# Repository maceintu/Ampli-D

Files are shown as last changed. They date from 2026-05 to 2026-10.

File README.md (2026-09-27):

# Ampli-D

Amplificateur audio stéréo **classe D** open hardware : entrées filaires et Bluetooth, DAC audiophile,
pilotage par microcontrôleur STM32. Le dépôt contient l'ensemble de la conception — schémas, PCB et firmware.

> **État du projet :** conception matérielle terminée côté schémas, routage du PCB en cours,
> firmware au stade du squelette généré (STM32CubeMX).

---

## Aperçu

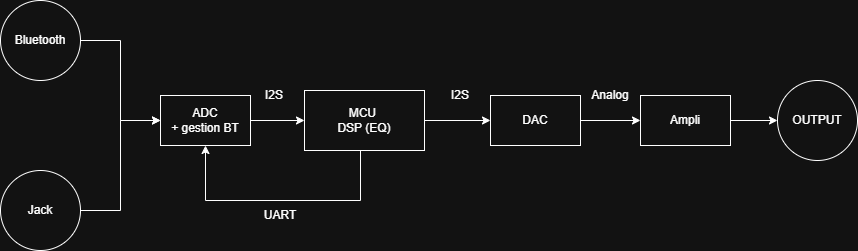
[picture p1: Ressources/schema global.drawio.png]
Schéma global


## Caractéristiques

| Bloc | Composant principal | Rôle |
|---|---|---|
| **Amplification** | TI **TPA3255** (DDV) | Étage de puissance classe D stéréo, filtres de sortie 10 µH / 25 A |
| **DAC** | TI **PCM5242** | Conversion I2S → analogique différentiel, sortie directe vers l'ampli |
| **Sélecteur de source** | TI **TMUX1574** | Aiguillage des flux I2S (filaire / Bluetooth) |
| **Entrées filaires** | TI **PCM1863** | 3 entrées stéréo numérisées (jacks Neutrik NMJ4HFD2 + jack 3,5 mm) |
| **Bluetooth** | **FSC-BT1058** | Réception audio sans fil (I2S) + contrôle par UART |
| **Contrôle** | ST **STM32G030C8T6** | Sélection de source, volume/EQ via I2C, appairage BT, gestion des défauts |
| **Alimentation** | LM5017 · TLV76733 · LT3042 | 36–48 V d'entrée → 12 V → 3,3 V numérique + 3,3 V analogique faible bruit |

**Interface utilisateur :** commutateur rotatif 4 positions (source), bouton poussoir (appairage Bluetooth),
4 potentiomètres lus par l'ADC du STM32 (volume et égalisation).

## Structure du dépôt

```
Ampli-D/
├── Kicad Workspace/        # Projet KiCad 10 (schémas hiérarchiques + PCB 2 couches)
│   ├── alimentation.kicad_sch
│   ├── amplification.kicad_sch
│   ├── bluetooth.kicad_sch
│   ├── eq_and_dac.kicad_sch
│   ├── mcu.kicad_sch
│   ├── wired_input.kicad_sch
│   ├── Components Lib.kicad_sym    # Symboles personnalisés
│   ├── FootPrints.pretty/          # Empreintes personnalisées
│   └── Lib Import/                 # Symboles / empreintes / STEP fabricants
├── STM32 Workspace/        # Projet STM32CubeIDE (STM32G030C8T6)
│   ├── MCU.ioc                     # Configuration CubeMX
│   ├── Core/                       # Code applicatif
│   └── Drivers/                    # HAL STM32G0 + CMSIS
└── Ressources/             # Datasheets, modèles 3D, outils de calcul
```

## Alimentation

| Rail | Régulateur | Usage |
|---|---|---|
| 36 V / 48 V | entrée externe | PVDD du TPA3255 |
| 12 V | LM5017 (buck 100 V) | GVDD / pilotage de l'étage de puissance |
| 3,3 V | TLV76733 | Numérique (STM32, Bluetooth) |
| 3,3 V A | LT3042 (LDO ultra faible bruit) | Analogique (DAC, ADC) |

## Démarrage

**Matériel** — ouvrir le projet avec [KiCad](https://www.kicad.org/) **10.0 ou supérieur** :

```bash
kicad "Kicad Workspace/Kicad Workspace.kicad_pro"
```

**Firmware** — ouvrir `STM32 Workspace/` dans [STM32CubeIDE](https://www.st.com/en/development-tools/stm32cubeide.html),
puis compiler et flasher via ST-Link. La configuration des périphériques se modifie depuis `MCU.ioc`
(I2C1, USART1, ADC1 + DMA, TIM1).

## Feuille de route

- [x] Schémas des six blocs fonctionnels
- [x] Symboles et empreintes des composants clés (TPA3255, PCM5242, FSC-BT1058, inductances de sortie)
- [ ] Routage complet du PCB
- [ ] Firmware : sélection de source, contrôle I2C du DAC/ADC, lecture des potentiomètres, gestion des défauts
- [ ] Fabrication et validation du premier prototype

## Ressources

Les datasheets de tous les circuits intégrés sont regroupées dans
[`Ressources/Datasheet/`](Ressources/Datasheet/), nommées par leur référence dans le schéma
(`U1_FSC-BT1058.pdf`, `U5_TPA3255.pdf`…). Le sous-dossier `txt/` en contient le texte intégral,
balisé page par page, pour pouvoir chercher dans l'ensemble de la documentation d'un seul coup :

```bash
grep -rn "bootstrap" Ressources/Datasheet/txt/
```

L'index [`Ressources/Datasheet/README.md`](Ressources/Datasheet/README.md) donne pour chaque
composant son rôle, la révision du document et la page où trouver brochage, maxima absolus,
caractéristiques électriques, layout et table des registres.

Le classeur `LM5017QuickStartCalculator.xls` sert au dimensionnement du convertisseur.

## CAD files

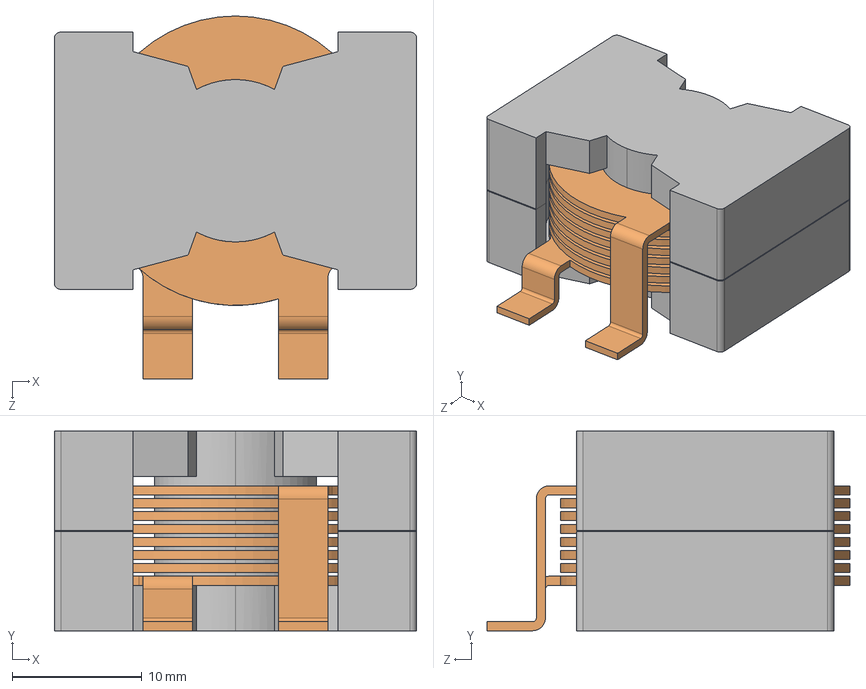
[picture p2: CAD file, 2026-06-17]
Kicad Workspace/Lib Import/SER2915L-103KL.step
27.9 x 15.4 x 27.9 mm

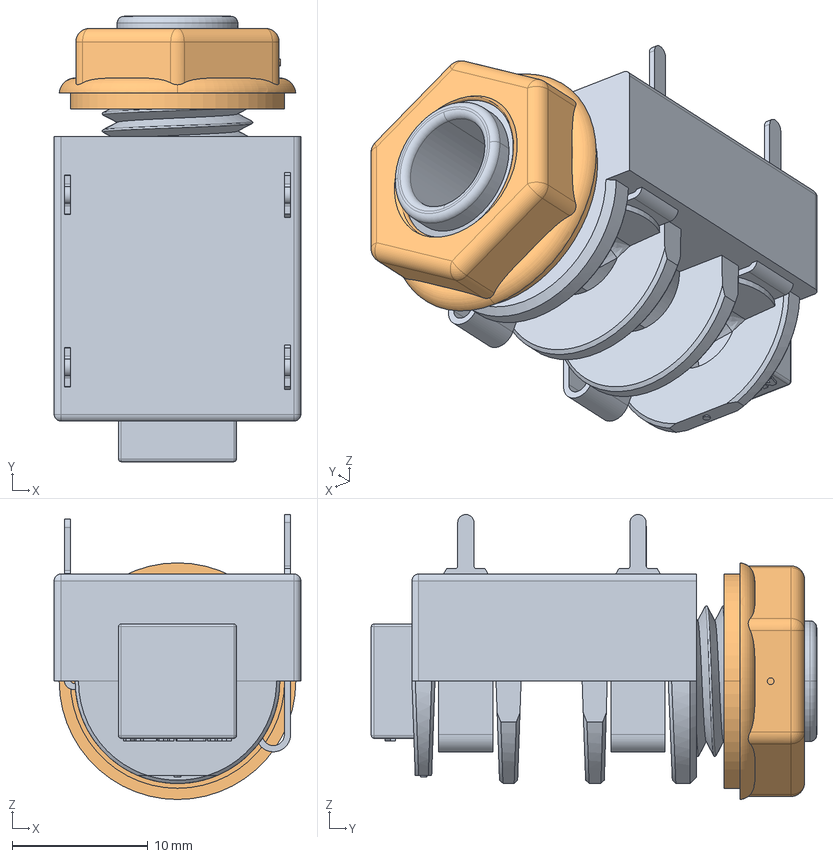
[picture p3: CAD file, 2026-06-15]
Ressources/3D Model NMJ4HFD2.stp
18.2 x 32.9 x 21.0 mm

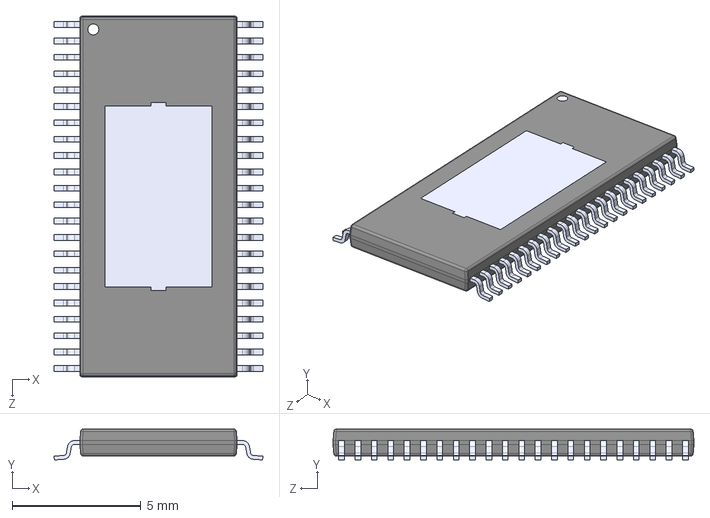
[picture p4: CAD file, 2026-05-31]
Kicad Workspace/Lib Import/TPA3255DDV.step
8.10 x 1.20 x 14.0 mm

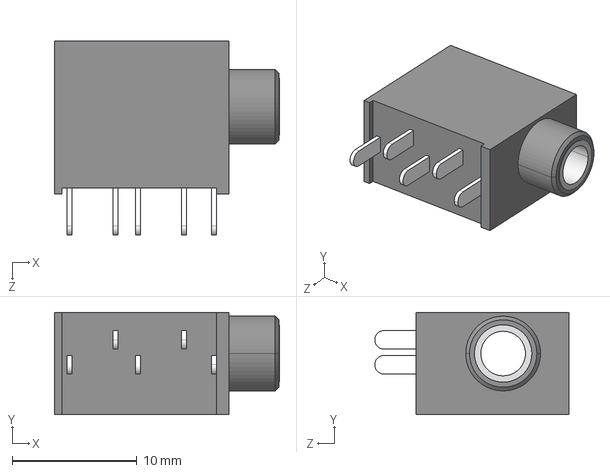
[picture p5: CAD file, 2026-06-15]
Ressources/Same_Sky_SJ1-3535NG.step
18.1 x 8.20 x 15.6 mm

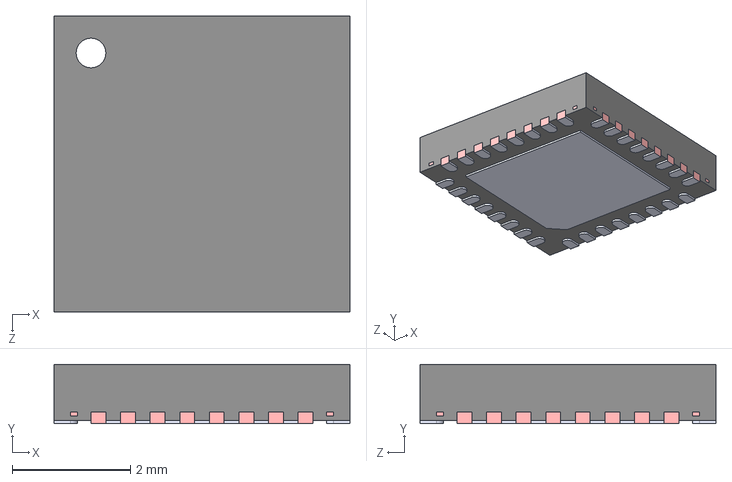
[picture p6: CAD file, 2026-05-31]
Kicad Workspace/Lib Import/PCM5242RHBT.step
5.00 x 1.00 x 5.00 mm

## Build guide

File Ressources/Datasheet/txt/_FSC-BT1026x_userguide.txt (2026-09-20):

# _FSC-BT1026x_userguide — 32 pages

===== page 1 =====
Shenzhen Feasycom Co.,Ltd.
 
1 

FSC-BT1026x User Guide
Feasycom
1.0

===== page 2 =====
Shenzhen Feasycom Co.,Ltd.
Table of contents
1 Hardware Design 2
1.1 Module Pin Diagram . . . . . . . . . . . . . . . . . . . . . . . . . . . . . . . 2
1.2 Pin Description . . . . . . . . . . . . . . . . . . . . . . . . . . . . . . . . . . 4
1.3 Power-on Circuit Design . . . . . . . . . . . . . . . . . . . . . . . . . . . . . 4
1.4 Hardware Design Note . . . . . . . . . . . . . . . . . . . . . . . . . . . . . . 5
2 Functional Description 6
2.1 Default Configuration . . . . . . . . . . . . . . . . . . . . . . . . . . . . . . . 6
2.2 Audio Algorithm Support Instructions . . . . . . . . . . . . . . . . . . . . . . 7
2.3 Supported Profiles . . . . . . . . . . . . . . . . . . . . . . . . . . . . . . . . 7
2.4 GATT Service . . . . . . . . . . . . . . . . . . . . . . . . . . . . . . . . . . 8
3 Quick Development Kit 9
3.1 Datasheet . . . . . . . . . . . . . . . . . . . . . . . . . . . . . . . . . . . . . 9
3.2 Evaluation Board . . . . . . . . . . . . . . . . . . . . . . . . . . . . . . . . . 9
3.3 AT Commands Set . . . . . . . . . . . . . . . . . . . . . . . . . . . . . . . . 9
3.4 Serial Port Tool . . . . . . . . . . . . . . . . . . . . . . . . . . . . . . . . . . 9
3.5 APP&SDK . . . . . . . . . . . . . . . . . . . . . . . . . . . . . . . . . . . . 10
3.6 Firmware Upgrade . . . . . . . . . . . . . . . . . . . . . . . . . . . . . . . . 10
3.6.1 OTA Upgrade . . . . . . . . . . . . . . . . . . . . . . . . . . . . . . 10
3.6.2 UART Upgrade . . . . . . . . . . . . . . . . . . . . . . . . . . . . . 10
4 Quick Start 11
4.1 What you need . . . . . . . . . . . . . . . . . . . . . . . . . . . . . . . . . . 11
4.1.1 Required Hardware . . . . . . . . . . . . . . . . . . . . . . . . . . . 11
4.1.2 Software and Setup . . . . . . . . . . . . . . . . . . . . . . . . . . . 11
4.2 Hardware Access . . . . . . . . . . . . . . . . . . . . . . . . . . . . . . . . . 11
4.3 Communication Test . . . . . . . . . . . . . . . . . . . . . . . . . . . . . . . 13
4.3.1 AT - UART Communication Test . . . . . . . . . . . . . . . . . . . . 13
4.3.2 AT+NAME - Read/Write Local BR/EDR Name . . . . . . . . . . . . 14
i

===== page 3 =====
Shenzhen Feasycom Co.,Ltd.
4.3.3 AT+LENAME - Read/Write Local BLE Name . . . . . . . . . . . . . 14
4.3.4 AT+VER - Read the Current Firmware Version . . . . . . . . . . . . 14
5 Obtain Firmware Version 15
5.1 FeasyBlue APP . . . . . . . . . . . . . . . . . . . . . . . . . . . . . . . . . . 15
5.2 UART AT Command . . . . . . . . . . . . . . . . . . . . . . . . . . . . . . . 16
6 Development Examples 17
6.1 Profile Initialization . . . . . . . . . . . . . . . . . . . . . . . . . . . . . . . . 17
6.2 Parameter Modification . . . . . . . . . . . . . . . . . . . . . . . . . . . . . . 18
6.2.1 Modify Bluetooth Name . . . . . . . . . . . . . . . . . . . . . . . . 18
6.3 Auido Sink Mode Application . . . . . . . . . . . . . . . . . . . . . . . . . . 19
6.3.1 Profile Connection . . . . . . . . . . . . . . . . . . . . . . . . . . . . 20
6.3.2 Play and Pause Music . . . . . . . . . . . . . . . . . . . . . . . . . . 21
6.3.3 Take and Hang up Call . . . . . . . . . . . . . . . . . . . . . . . . . 22
6.4 Phonebook Download . . . . . . . . . . . . . . . . . . . . . . . . . . . . . . 22
6.4.1 HFP connection has been established . . . . . . . . . . . . . . . . . . 22
6.4.2 Download all phonebooks . . . . . . . . . . . . . . . . . . . . . . . . 23
6.4.3 Download 50 call records . . . . . . . . . . . . . . . . . . . . . . . . 23
7 Firmware Upgrade 24
7.1 OTA Upgrade . . . . . . . . . . . . . . . . . . . . . . . . . . . . . . . . . . . 24
7.1.1 Tool . . . . . . . . . . . . . . . . . . . . . . . . . . . . . . . . . . . 24
7.1.2 User Guide . . . . . . . . . . . . . . . . . . . . . . . . . . . . . . . 24
7.1.3 OTA Upgrade Example . . . . . . . . . . . . . . . . . . . . . . . . . 25
7.2 UART Upgrade . . . . . . . . . . . . . . . . . . . . . . . . . . . . . . . . . . 25
7.2.1 Tool . . . . . . . . . . . . . . . . . . . . . . . . . . . . . . . . . . . 26
7.2.2 User Guide . . . . . . . . . . . . . . . . . . . . . . . . . . . . . . . 26
7.2.3 UART Upgrade Example . . . . . . . . . . . . . . . . . . . . . . . . 26
7.3 FAQs . . . . . . . . . . . . . . . . . . . . . . . . . . . . . . . . . . . . . . . 27
8 Contact Information 28
9 Appendix 29
9.1 PDF Dowload . . . . . . . . . . . . . . . . . . . . . . . . . . . . . . . . . . . 29
ii

===== page 4 =====
Shenzhen Feasycom Co.,Ltd.
FSC-BT1026x User Guide
[中文版]
This guide is applicable to the FSC-BT1026x series Bluetooth audio module, include:
• FSC-BT1026A
• FSC-BT1026B
• FSC-BT1026C
• FSC-BT1026D
• FSC-BT1026E
• FSC-BT1026F
This guide consists of the following parts:
Table of contents 1

===== page 5 =====
Shenzhen Feasycom Co.,Ltd.
Chapter 1
Hardware Design
[中文版]
1.1 Module Pin Diagram
Taking FSC-BT1026C as an example:
2

===== page 6 =====
Shenzhen Feasycom Co.,Ltd.
FSC-BT1026x User Guide
1.1. Module Pin Diagram 3

===== page 7 =====
Shenzhen Feasycom Co.,Ltd.
FSC-BT1026x User Guide
1.2 Pin Description
Pin Pin Name Type Pin Descriptions
4 I2S_CLK I/O I2S BCLK
5 I2S_IN I I2S DATA IN
6 I2S_OUT O I2S DATA OUT
7 I2S_WS I/O I2S SYNC
8 RESET I Low level reset
13 UART_TX O UART_TX
14 UART_RX I UART_RX
15 UART_CTS I/O UART flow control pin (not required by default)
16 UART_RTS I/O default as power amplifier control pin
17 LED0 I/O General-purpose analog/digital input or output.
18 LED1 I/O General-purpose analog/digital input or output
32 GND GND GND
33 VDD VDD 3.3V power supply, it is recommended to use LDO
34 SYS_CTRL I Power on/off pin
36 VDD_IO I pio supply
43 MIC_LP Audio MIC0/Line_IN differential L input, positive
44 MIC_LN Audio MIC0/Line_IN differential L input, negative
45 MIC_BIAS Audio MIC Power Supplies
46 SPK_RN Audio Headphone/speaker differential R output, negative
47 SPK_RP Audio Headphone/speaker differential R output, positive
48 SPK_LN Audio Headphone/speaker differential L output, negative
49 SPK_LP Audio Headphone/speaker differential L output, positive
51 EXT_ANT ANT External antenna connect pin
1.3 Power-on Circuit Design
The FSC-BT1026X module has three options for power on, which are: delayed power on cir-
cuit, button on/off circuit, and MCU controlled power on/off circuit. As shown in the following
figure:
1.2. Pin Description 4

===== page 8 =====
Shenzhen Feasycom Co.,Ltd.
FSC-BT1026x User Guide
1.4 Hardware Design Note
• simple testing environment, just connect VDD / VDD_IO / SYS_CTRL / GND /
UART_RX / UART_TX.
• SYS_CTRL defaults to key on/off mode. Power on: Short press for 1 second Power off:
Press and hold for 3 seconds.
• If the button on/off mode is not used, power on delay of 100ms and then raise
SYS_CTRL.
• After drawing the PCB circuit schematic, please send it to Feasycom for review to avoid
suboptimal Bluetooth distance.
1.4. Hardware Design Note 5

===== page 9 =====
Shenzhen Feasycom Co.,Ltd.
Chapter 2
Functional Description
[中文版]
2.1 Default Configuration
Name FSC-BT1026-XXXX
LE-Name FSC-BT1026-LE-XXXX
Pin Code 0000
Secure Simple Pairing Mode On
UART Baudrate 115200/8/N/1
6

===== page 10 =====
Shenzhen Feasycom Co.,Ltd.
FSC-BT1026x User Guide
2.2 Audio Algorithm Support Instructions
model chip SBC AAC aptX aptX-
HD
aptX-
LL
aptX-
AD
aptX-
LossLess
LDAC CVC
BT1026BQCC3031√ √ √ √ li-
cense
× × × √
BT1026CQCC3024√ √ li-
cense
× × × × × √
BT1026DQCC3034√ √ √ √ li-
cense
× × × √
BT1026EQCC5125√ √ li-
cense
license li-
cense
li-
cense
× √ li-
cense
BT1026FQCC5124√ √ li-
cense
license li-
cense
li-
cense
× × li-
cense
• FSC-BT1026B & FSC-BT1026D ：APTX-LL requires the purchase of a license, which
is not supported by the default program. If you need to test APTX-LL, please contact
Feasycom.
• FSC-BT1026E ：The APTX series decoding (including APTX, APTX-HD, APTX-LL,
APTX-AD) and CVC all require authorization licenses.
2.3 Supported Profiles
• SPP (Serial Port Profile)
• GATTS (Generic Attribute Profile LE-Peripheral role)
• HFP-HF (Hands-Free Profile)
• A2DP-Sink (Advanced Audio Distribution Profile)
• AVRCP-Controller (Audio/Video remote controller Profile)
• HID-DEVICE (Human Interface Profile)
• PBAP (Phonebook Access Profile)
2.2. Audio Algorithm Support Instructions 7

===== page 11 =====
Shenzhen Feasycom Co.,Ltd.
FSC-BT1026x User Guide
2.4 GATT Service
Type UUID Operation Description
Service 0xFFF0 Throughput transmission service
Write 0xFFF2 Write,Write Without Response APP sends data to module
Notify 0xFFF1 Notify App notification
2.4. GATT Service 8

===== page 12 =====
Shenzhen Feasycom Co.,Ltd.
Chapter 3
Quick Development Kit
[中文版]
3.1 Datasheet
• FSC-BT1026x Datasheet
3.2 Evaluation Board
• FSC-DB200 ：Feasycom Bluetooth audio application development board, compatible with
FSC-BT1026x series modules.
3.3 AT Commands Set
• FSC-BT1026x General Audio AT Commands Set
• FSC-BT1026x TWS AT Commands Set
3.4 Serial Port Tool
• Feasycom Serial Port Tool : A serial port communication analysis tool based on Windows
PC.
9

===== page 13 =====
Shenzhen Feasycom Co.,Ltd.
FSC-BT1026x User Guide
3.5 APP&SDK
• FeasyBlue ：Feasycom App & SDK resource supporting Android and iOS, which enables
functions such as Bluetooth BLE & SPP data communication test, Feasycom module
firmware version reading, and parameter configuration and OTA AT commands etc.
3.6 Firmware Upgrade
3.6.1 OTA Upgrade
• FeasyOTA App (Based on Mobile Application)
• User Guide: Please refer to FSC-BT1026x - OTA Upgrade
3.6.2 UART Upgrade
• FSC-BT1038x Upgrade Tool (Based on Windows PC)
• User Guide: Please refer to FSC-BT1026x - UART Upgrade 。
3.5. APP&SDK 10

===== page 14 =====
Shenzhen Feasycom Co.,Ltd.
Chapter 4
Quick Start
[中文版]
4.1 What you need
4.1.1 Required Hardware
• 1 x FSC-DB200-BT1026C Rapid Development Kit : FSC-DB200 Rapid Development
Kit pre-integrated with the FSC-BT1026C Bluetooth Audio Module
• 1 x PC (Windows)
4.1.2 Software and Setup
• Feasycom Serial Port Tool : A serial port communication analysis tool based on Windows
PC.
• Communication Interface : UART
• UART Configuration：115200/8/N/1
4.2 Hardware Access
1. Connect FSC-DB200-BT1026C to PC via USB To Type-C cable, switch the
UART/USB toggle to UART,Press the USB/battery power option button to switch to
USB power supply, Press and hold the ON/OFF button for 3 seconds to turn on the de-
vice, and the PC will automatically recognize the serial port and generate a virtual COMx
port.
11

===== page 15 =====
Shenzhen Feasycom Co.,Ltd.
FSC-BT1026x User Guide
2. Run the Feasycom Serial Port Tool on the PC, set the correct COM and Baud, and
check the New Line.
4.2. Hardware Access 12

===== page 16 =====
Shenzhen Feasycom Co.,Ltd.
FSC-BT1026x User Guide
4.3 Communication Test
The following are several basic general AT command test examples.
For more AT commands, please refer to FSC-BT1026x General Audio AT Commands Set .
4.3.1 AT - UART Communication Test
Com-
mand
AT\r\n
Response \r\nOK\r\n
Descrip-
tion
Test the UART communication between HOST and Module after power on,
baudrate changed, etc.
Example:
Send: >>AT\r\n
Response: <<\r\nOK\r\n //Successfully connected .
4.3. Communication Test 13

===== page 17 =====
Shenzhen Feasycom Co.,Ltd.
FSC-BT1026x User Guide
4.3.2 AT+NAME - Read/Write Local BR/EDR Name
Example：
Send: >>AT+NAME\r\n
Response: <<\r\n+NAME=FSC-BT1026C\r\n //Example, please refer ␣
,→to the actual reading
Response: <<\r\nOK\r\n
4.3.3 AT+LENAME - Read/Write Local BLE Name
Example：
Send: >>AT+LENAME\r\n
Response: <<\r\n+LENAME=FSC-BT1026C-LE\r\n //Example, please ␣
,→refer to the actual reading
Response: <<\r\nOK\r\n
4.3.4 AT+VER - Read the Current Firmware Version
Example：
Send: >>AT+VER\r\n
Response: <<\r\n+VER=FSC-BT1026C,V4.9.4\r\n //Example, please ␣
,→refer to the actual reading result
Response: <<\r\nOK\r\n
4.3. Communication Test 14

===== page 18 =====
Shenzhen Feasycom Co.,Ltd.
Chapter 5
Obtain Firmware Version
[中文版]
5.1 FeasyBlue APP
After establishing BLE connection with the FSC-BT1026x through FeasyBlue APP, check the
firmware version information on the Transmission Configuration function interface.
Warning：The profile of the Bluetooth module needs to enable BLE (GATT) function
15

===== page 19 =====
Shenzhen Feasycom Co.,Ltd.
FSC-BT1026x User Guide
5.2 UART AT Command
Send the AT+VER command through UART to obtain firmware version information.
The example of AT command operation and response events is as follows:
Send: >>AT+VER
Response: << +VER=FSC-BT1026C,V4.9.4 //Example, please refer to ␣
,→the actual reading result
5.2. UART AT Command 16

===== page 20 =====
Shenzhen Feasycom Co.,Ltd.
Chapter 6
Development Examples
[中文版]
6.1 Profile Initialization
Module Profile initialization, response event examples are as follows:
17

===== page 21 =====
Shenzhen Feasycom Co.,Ltd.
FSC-BT1026x User Guide
6.2 Parameter Modification
6.2.1 Modify Bluetooth Name
Before the MCU modifies any parameters, it is recommended to first query, then modify, and
finally verify. For the MCU to modify the device name to CARKIT, the reference code exam-
ple is as follows:
void change_name(void)
{
uart_send("AT+NAME\r\n");
if(uart_read("+NAME",name_buf))
{
if(memcmp(name_buf,"CARKIT",6))
{
uart_send("AT+NAME=CARKIT,0\r\n"); //defalut disable ␣
,→MAC address suffix
uart_send("AT+NAME\r\n"); // read bt name
if(uart_read("+NAME",name_buf))
{
if(memcmp(name_buf,"CARKIT",6))
{
(continues on next page)
6.2. Parameter Modification 18

===== page 22 =====
Shenzhen Feasycom Co.,Ltd.
FSC-BT1026x User Guide
(continued from previous page)
//change name fail
}
else
{
//change name success
}
}
}
}
}
6.3 Auido Sink Mode Application
6.3. Auido Sink Mode Application 19

===== page 23 =====
Shenzhen Feasycom Co.,Ltd.
FSC-BT1026x User Guide
6.3.1 Profile Connection
6.3. Auido Sink Mode Application 20

===== page 24 =====
Shenzhen Feasycom Co.,Ltd.
FSC-BT1026x User Guide
6.3.2 Play and Pause Music
6.3. Auido Sink Mode Application 21

===== page 25 =====
Shenzhen Feasycom Co.,Ltd.
FSC-BT1026x User Guide
6.3.3 Take and Hang up Call
6.4 Phonebook Download
Application Process Operation Examples:
6.4.1 HFP connection has been established
Response: <<+PWRSTAT=1
Response: <<+VER=FSC-BT1026C,V4.9.4,20230428 // Example, please ␣
,→refer to the actual version
Response: <<+PROFILE=1195 // General default, enable SPP, ␣
,→GATT Server, HFP -HF, A2DP Sink, AVRCP Controller, PBAP Server ␣
,→profiles
(continues on next page)
6.4. Phonebook Download 22

===== page 26 =====
Shenzhen Feasycom Co.,Ltd.
FSC-BT1026x User Guide
(continued from previous page)
Response: <<+SPPSTAT=1
Response: <<+GATTSTAT=1
Response: <<+A2DPSTAT=1
Response: <<+AVRCPSTAT=1
Response: <<+HFPSTAT=1
Response: <<+AVRCPSTAT=1
Response: <<+PBSTAT=1
Response: <<+DEVSTAT=1
Response: <<+DEVSTAT=7 // Enables device discoverability; ␣
,→mobile phones can find this Bluetooth device and establish a ␣
,→connection
6.4.2 Download all phonebooks
Send : >>AT+PBDOWN=1
Response: <<OK
Response: <<+PBSTAT=2
Response: <<+PBSTAT=3 // PBAP connected
Response: <<+PBSTAT=4 // PBAP downloading
Response: <<+PBDATA=1<FF>Local Number <FF>+8618620277272
Response: <<+PBDATA=1<FF>Zhang San <FF>0571-85592192
...
Response: <<+PBDATA=1<FF>Jerry<FF>18909731215
Response: <<+PBDATA=E // Download completed
Response: <<+PBSTAT=3
6.4.3 Download 50 call records
Send: >>AT+PBWODN=5,50
Response: <<ok
Response: <<+PBDATA=3<FF>yidong<FF>+10086<FF>20200213T114247
...
Response: <<+PBDATA=2<FF>andy<FF>85592192<FF>20200212T104202
Response: <<+PBDATA=E // Download completed
Response: <<+PBSTAT=3
6.4. Phonebook Download 23

===== page 27 =====
Shenzhen Feasycom Co.,Ltd.
Chapter 7
Firmware Upgrade
[中文版]
FSC-BT1026x series Bluetooth audio module now supports : Over the air upgrade (OTA)
and Uart upgrade.
7.1 OTA Upgrade
7.1.1 Tool
• FeasyOTA APP (Based on Android)
7.1.2 User Guide
1.Run FeasyOTA APP. On the home screen, select the BT1026x Upgrade (Universal Ver-
sion) function module. After entering, you will be navigated to the device search interface.
2.Search for and find the name of the Bluetooth module that needs upgrading (e.g., FSC-
BT1026C). Selecting the device will automatically initiate Bluetooth pairing and connection.
If Disconnect is displayed in the top-right corner of the screen, it indicates that the device is
fully connected. If Connect is displayed, it means the device is not fully connected; please click
Connect in the top-right corner to ensure a complete connection.
3.On the successfully connected screen, the Upgrade button will be displayed and clickable.
4.Click the Upgrade button. In the pop-up OTA Upgrade interface, load the firmware upgrade
file in one of the following ways:
• Via Select Firmware: Choose the firmware upgrade file stored in the mobile phone ’s
local storage (provided by Feasycom).
24

===== page 28 =====
Shenzhen Feasycom Co.,Ltd.
FSC-BT1026x User Guide
• Via Get Firmware: Enter the DFU Name to download the firmware file from the Feasy-
com cloud server for upgrade. The DFU Name is in a path format similar to /BT1026C/
audrx/test (example, please refer to the actual information provided by Feasycom).
5.After the firmware file is successfully loaded, click the Start Upgrade button. The interface
will display the upgrade progress and “Upgrading”, indicating that the upgrade mode is suc-
cessfully entered and the upgrade is in progress.
6.Wait for the upgrade progress bar to complete. When “Upgrade Completed”is displayed,
the upgrade is finished.
Warning：
1. When installing and running FeasyOTA App, please allow the app to obtain permissions
such as nearby devices, location information, media and file access, otherwise it may
not be able to find nearby Bluetooth devices or load firmware files;
2. If enter DFU name to obtain upgrade files, you need to pay attention to the phone ’s
access to the Internet and ensure that the DFU name is entered correctly (case sensitive),
otherwise an error network or file error will be reported;
3. Do not turn off the power during the upgrade process
7.1.3 OTA Upgrade Example
7.2 UART Upgrade
7.2. UART Upgrade 25

===== page 29 =====
Shenzhen Feasycom Co.,Ltd.
FSC-BT1026x User Guide
7.2.1 Tool
• FSC-BT1038x Upgrade Tool 2.1 (Based on Windows PC)
7.2.2 User Guide
1.This example uses the Feasycom FSC-DB200 development board.
2.Connect the FSC-DB200-BT1026C to the PC via a USB to Type-C data cable. Toggle the
UART/USB switch to UART, press the USB/Battery Power Option button to switch to
USB, and press and hold the Power (ON/OFF) button for 2-3 seconds to power on. The PC
will automatically recognize the serial port and generate a virtual COMx port.
3.Open FSC-BT1038x Upgrade Tool. Click Browse to select the firmware upgrade file stored
locally on the PC to load the firmware file.
4.After loading the firmware file, select the corresponding COMx for the Port, and select the
current baud rate of the module for the BaudRate (the default baud rate for general is 115200).
Once the configurations are confirmed to be correct, click Upgrade to start the upgrade and
enter upgrade mode. Wait until the “Status and Progress”bar is complete.
7.2.3 UART Upgrade Example
7.2. UART Upgrade 26

===== page 30 =====
Shenzhen Feasycom Co.,Ltd.
FSC-BT1026x User Guide
7.3 FAQs
Q：What should I do if there is an exception during the upgrade process, such as an upgrade in-
terruption? After the upgrade is completed, but the module has not been successfully upgraded
A：You can try powering on again and repeating the upgrade operation
to confirm if you can enter the upgrade mode normally. If not, please
contact the Feasycom support team.
Q：How to achieve firmware upgrade of FSC-BT1026x through MCU UART?
A：Customers are required to integrate the upgrade protocol into the
MCU. If you have this requirement, please contact the Feasycom sup-
port team (email: Feasycom@support.com ）
7.3. FAQs 27

===== page 31 =====
Shenzhen Feasycom Co.,Ltd.
Chapter 8
Contact Information
Shenzhen Feasycom Co.,Ltd.
Address : Rm 508, Building, Fenghuang Zhigu, NO.50, Tiezai Road, Xixiang, Baoan Dist,
Shenzhen, 518100, China.
Telephone : 86-755-23062695
Support : support@feasycom.com
Sales Service : sales@feasycom.com
Home Page : www.feasycom.com
Support Forum : forum.feasycom.com
28

===== page 32 =====
Shenzhen Feasycom Co.,Ltd.
Chapter 9
Appendix
9.1 PDF Dowload
PDF download
29

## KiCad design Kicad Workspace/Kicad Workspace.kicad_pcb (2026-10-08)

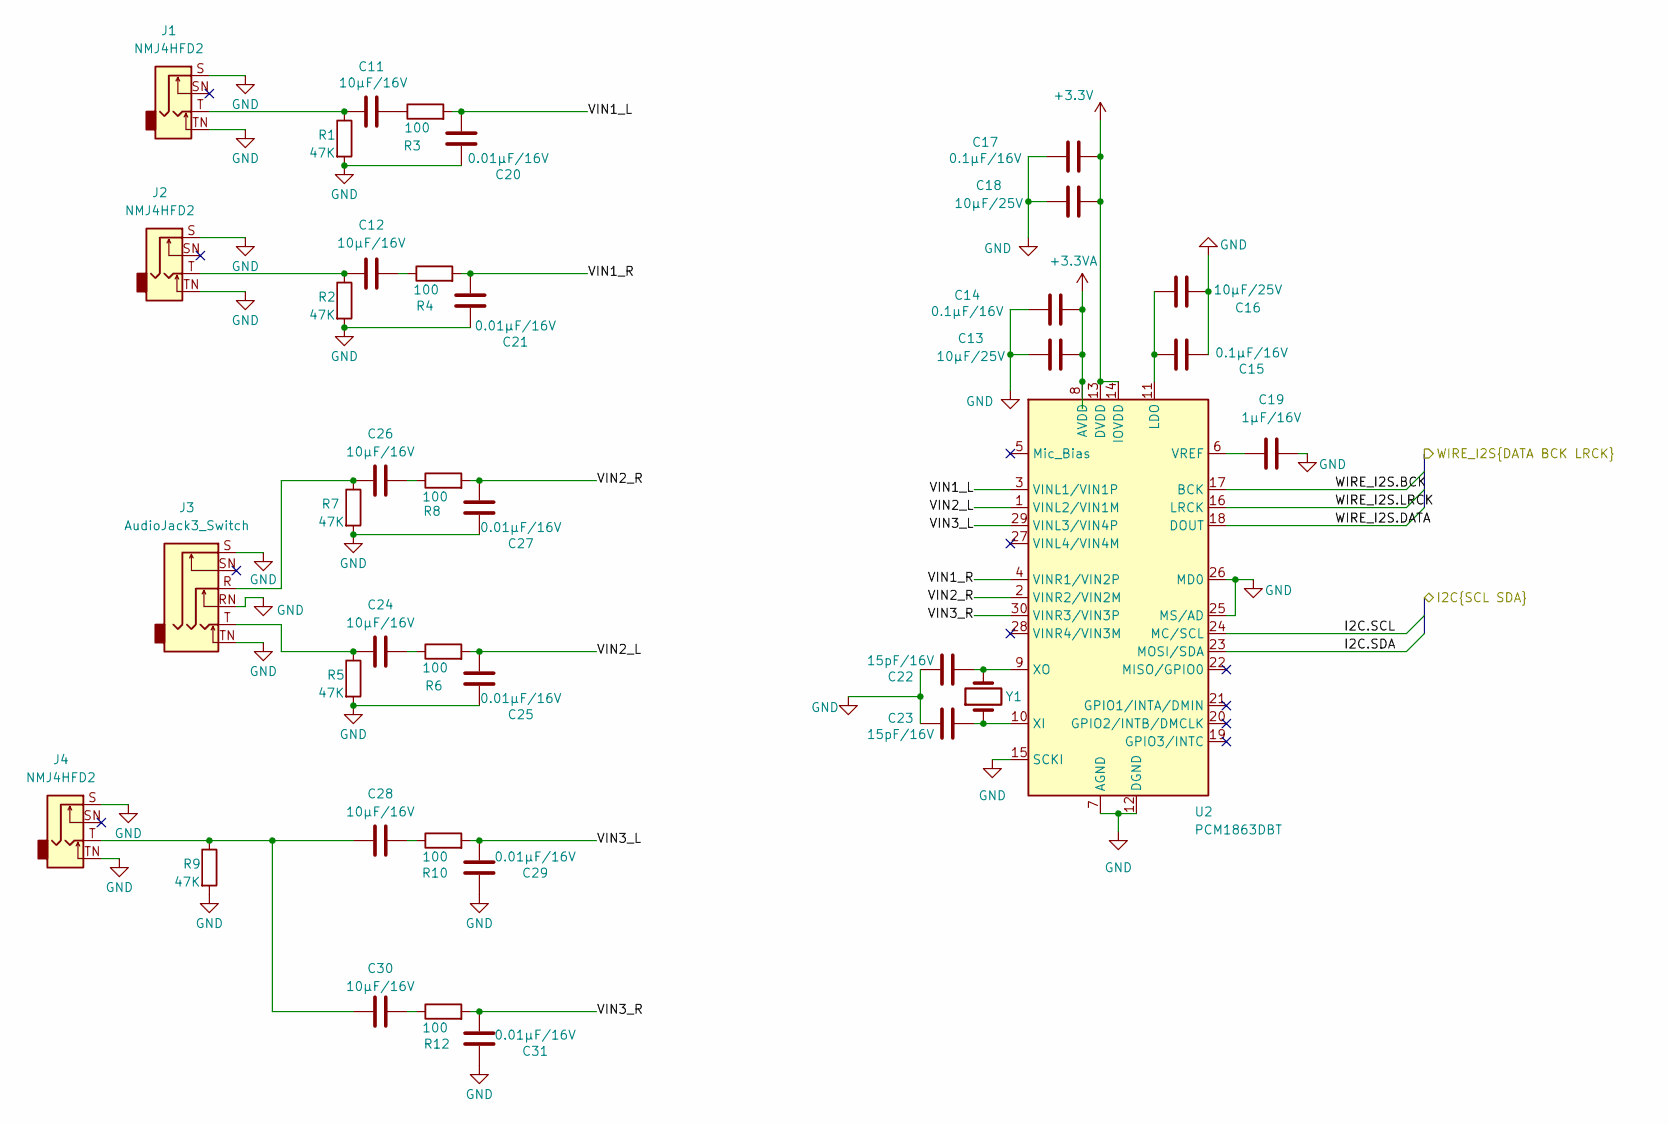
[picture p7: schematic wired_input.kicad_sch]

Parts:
C11, C12, C24, C26, C28, C30: 10µF/16V; C_0805_2012Metric
C13, C16, C18: 10µF/25V; C_0805_2012Metric
C14, C15, C17: 0.1µF/16V; C_0402_1005Metric
C19: 1µF/16V; C_0805_2012Metric
C20, C21, C25, C27, C29, C31: 0.01µF/16V; C_0402_1005Metric
C22, C23: 15pF/16V; C_0402_1005Metric
J1, J2, J4: NMJ4HFD2; Jack_6.35mm_Neutrik_NMJ4HFD2_Horizontal
J3: AudioJack3_Switch; Jack_3.5mm_CUI_SJ1-3535NG_Horizontal
R1, R2, R5, R7, R9: 47K; R_01005_0402Metric
R3, R4, R6, R8, R10, R12: 100; R_01005_0402Metric
U2: PCM1863DBT; TSSOP-30_4.4x7.8mm_P0.5mm
Y1: Crystal

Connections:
+3.3V: C17.1, C18.1, U2.13 (DVDD), U2.14 (IOVDD); also elsewhere on the board
+3.3VA: C13.1, C14.1, U2.8 (AVDD); also elsewhere on the board
/EQ and DAC/I2C.SCL: U2.24 (MC/SCL); also elsewhere on the board
/EQ and DAC/I2C.SDA: U2.23 (MOSI/SDA); also elsewhere on the board
/EQ and DAC/WIRE_I2S.BCK: U2.17 (BCK); also elsewhere on the board
/EQ and DAC/WIRE_I2S.DATA: U2.18 (DOUT); also elsewhere on the board
/EQ and DAC/WIRE_I2S.LRCK: U2.16 (LRCK); also elsewhere on the board
/Wired Input/VIN1_L: C20.1, R3.2, U2.3 (VINL1/VIN1P)
/Wired Input/VIN1_R: C21.1, R4.2, U2.4 (VINR1/VIN2P)
/Wired Input/VIN2_L: C25.1, R6.2, U2.1 (VINL2/VIN1M)
/Wired Input/VIN2_R: C27.1, R8.2, U2.2 (VINR2/VIN2M)
/Wired Input/VIN3_L: C29.1, R10.2, U2.29 (VINL3/VIN4P)
/Wired Input/VIN3_R: C31.1, R12.2, U2.30 (VINR3/VIN3P)
GND: C13.2, C14.2, C15.2, C16.2, C17.2, C18.2, C19.2, C20.2, C21.2, C22.2, C23.1, C25.2, C27.2, C29.2, C31.2, J1.S, J1.TN, J2.S, J2.TN, J3.RN, J3.S, J3.TN, J4.S, J4.TN, R1.2, R2.2, R5.2, R7.2, R9.2, U2.7 (AGND), U2.12 (DGND), U2.15 (SCKI), U2.25 (MS/AD), U2.26 (MD0); also elsewhere on the board
unnamed: C11.1, J1.T, R1.1
unnamed: C11.2, R3.1
unnamed: C12.1, J2.T, R2.1
unnamed: C12.2, R4.1
unnamed: C24.1, J3.T, R5.1
unnamed: C24.2, R6.1
unnamed: C26.1, J3.R, R7.1
unnamed: C26.2, R8.1
unnamed: C28.1, C30.1, J4.T, R9.1
unnamed: C28.2, R10.1
unnamed: C30.2, R12.1
unnamed: C15.1, C16.1, U2.11 (LDO)
unnamed: C19.1, U2.6 (VREF)
unnamed: C23.2, U2.10 (XI), Y1.1
unnamed: C22.1, U2.9 (XO), Y1.2

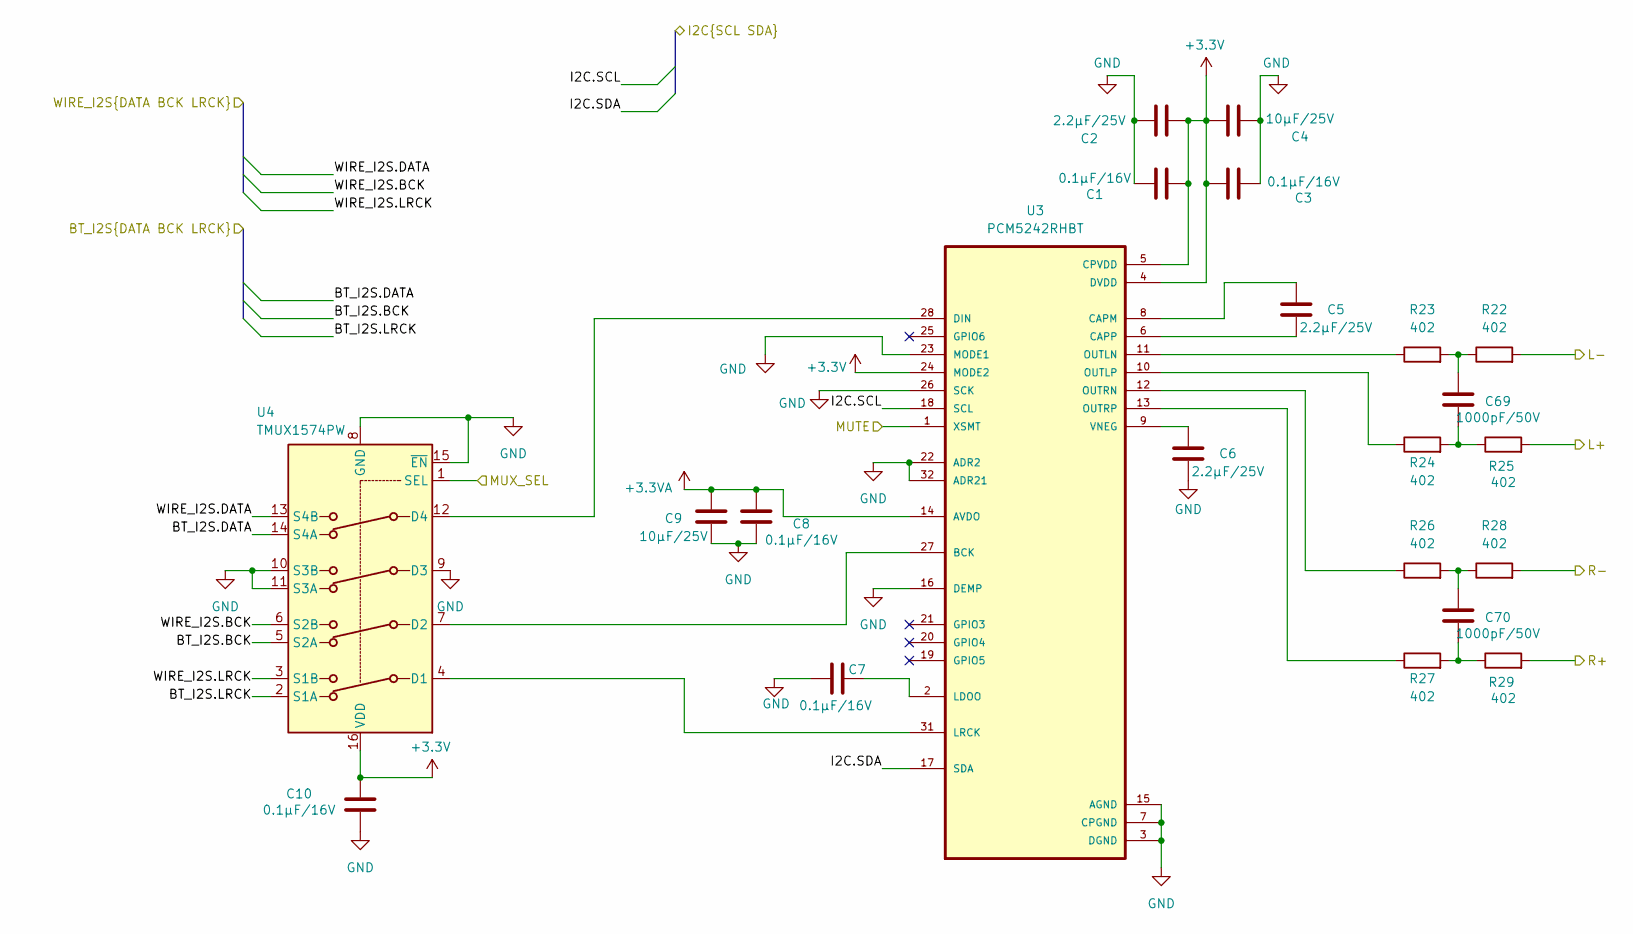
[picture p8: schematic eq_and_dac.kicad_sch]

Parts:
C1, C3, C7, C8, C10: 0.1µF/16V; C_0402_1005Metric
C2, C6: 2.2µF/25V; C_0805_2012Metric
C4, C9: 10µF/25V; C_0805_2012Metric
C5: 2.2µF/25V; C_0201_0603Metric
C69, C70: 1000pF/50V; C_0201_0603Metric
R22, R23, R24, R25, R26, R27, R28, R29: 402; R_0201_0603Metric
U3: PCM5242RHBT; PCM5242
U4: TMUX1574PW; TSSOP-16_4.4x5mm_P0.65mm

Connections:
+3.3V: C1.2, C2.2, C3.1, C4.1, C10.2, U3.4 (DVDD), U3.5 (CPVDD), U3.24 (MODE2), U4.16 (VDD); also elsewhere on the board
+3.3VA: C8.2, C9.2, U3.14 (AVDO); also elsewhere on the board
/Amplification/IN_L+: R25.2; also elsewhere on the board
/Amplification/IN_L-: R22.2; also elsewhere on the board
/Amplification/IN_R+: R29.2; also elsewhere on the board
/Amplification/IN_R-: R28.2; also elsewhere on the board
/Bluetooth/BT_I2S.BCK: U4.5 (S2A); also elsewhere on the board
/Bluetooth/BT_I2S.DATA: U4.14 (S4A); also elsewhere on the board
/Bluetooth/BT_I2S.LRCK: U4.2 (S1A); also elsewhere on the board
/EQ and DAC/I2C.SCL: U3.18 (SCL); also elsewhere on the board
/EQ and DAC/I2C.SDA: U3.17 (SDA); also elsewhere on the board
/EQ and DAC/MUTE: U3.1 (XSMT); also elsewhere on the board
/EQ and DAC/MUX_SEL: U4.1 (SEL); also elsewhere on the board
/EQ and DAC/WIRE_I2S.BCK: U4.6 (S2B); also elsewhere on the board
/EQ and DAC/WIRE_I2S.DATA: U4.13 (S4B); also elsewhere on the board
/EQ and DAC/WIRE_I2S.LRCK: U4.3 (S1B); also elsewhere on the board
GND: C1.1, C2.1, C3.2, C4.2, C6.2, C7.1, C8.1, C9.1, C10.1, U3.3 (DGND), U3.7 (CPGND), U3.15 (AGND), U3.16 (DEMP), U3.22 (ADR2), U3.23 (MODE1), U3.26 (SCK), U3.32 (ADR21), U4.8 (GND), U4.9 (D3), U4.10 (S3B), U4.11 (S3A), U4.15 (~EN); also elsewhere on the board
unnamed: C69.1, R24.2, R25.1
unnamed: C69.2, R22.1, R23.2
unnamed: C70.1, R27.2, R29.1
unnamed: C70.2, R26.2, R28.1
unnamed: U3.27 (BCK), U4.7 (D2)
unnamed: C5.1, U3.8 (CAPM)
unnamed: C5.2, U3.6 (CAPP)
unnamed: U3.28 (DIN), U4.12 (D4)
unnamed: C7.2, U3.2 (LDOO)
unnamed: U3.31 (LRCK), U4.4 (D1)
unnamed: R23.1, U3.11 (OUTLN)
unnamed: R24.1, U3.10 (OUTLP)
unnamed: R26.1, U3.12 (OUTRN)
unnamed: R27.1, U3.13 (OUTRP)
unnamed: C6.1, U3.9 (VNEG)

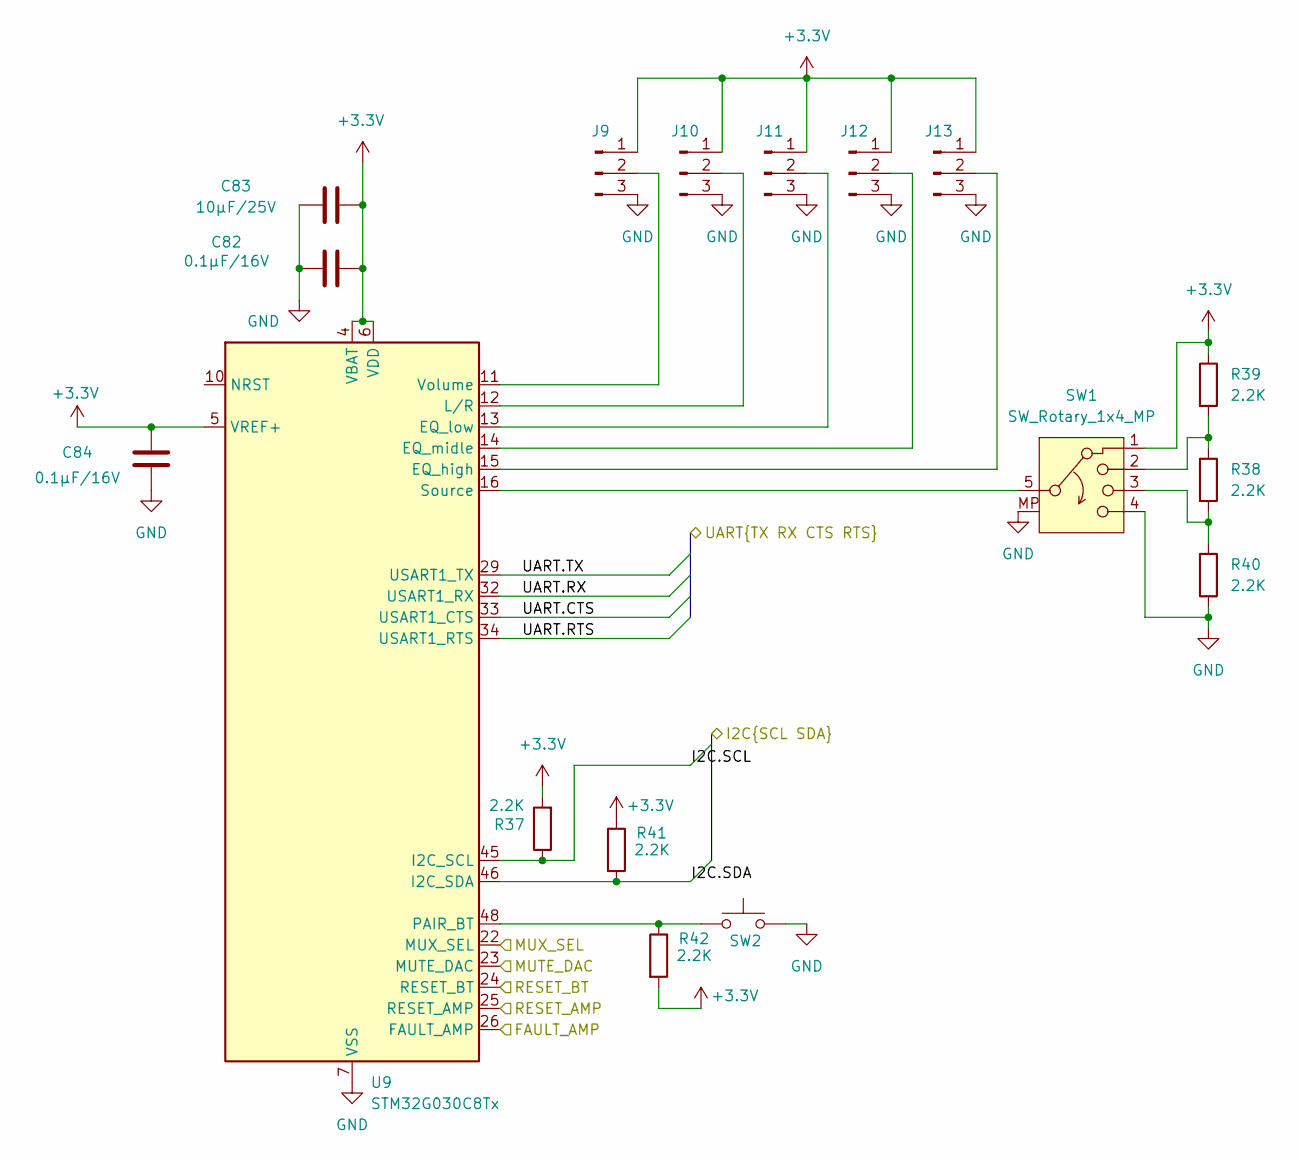
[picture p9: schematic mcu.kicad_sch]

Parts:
C82, C84: 0.1µF/16V; C_0402_1005Metric
C83: 10µF/25V; C_0805_2012Metric
J9, J10, J11, J12, J13: Conn_01x03_Pin; PinHeader_1x03_P2.54mm_Vertical
R37, R38, R39, R40, R41, R42: 2.2K; R_0201_0603Metric
SW1: SW_Rotary_1x4_MP
SW2: SW_PUSH_6mm
U9: STM32G030C8Tx; LQFP-48_7x7mm_P0.5mm

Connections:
+3.3V: C82.1, C83.1, C84.2, J9.1, J10.1, J11.1, J12.1, J13.1, R37.2, R39.1, R41.1, R42.2, SW1.1, U9.4 (VBAT), U9.5 (VREF+), U9.6 (VDD); also elsewhere on the board
/Amplification/FAULT: U9.26 (FAULT_AMP); also elsewhere on the board
/Amplification/RESET: U9.25 (RESET_AMP); also elsewhere on the board
/Bluetooth/BT_RESET: U9.24 (RESET_BT); also elsewhere on the board
/Bluetooth/UART.CTS: U9.33 (USART1_CTS); also elsewhere on the board
/Bluetooth/UART.RTS: U9.34 (USART1_RTS); also elsewhere on the board
/Bluetooth/UART.RX: U9.32 (USART1_RX); also elsewhere on the board
/Bluetooth/UART.TX: U9.29 (USART1_TX); also elsewhere on the board
/EQ and DAC/I2C.SCL: R37.1, U9.45 (I2C_SCL); also elsewhere on the board
/EQ and DAC/I2C.SDA: R41.2, U9.46 (I2C_SDA); also elsewhere on the board
/EQ and DAC/MUTE: U9.23 (MUTE_DAC); also elsewhere on the board
/EQ and DAC/MUX_SEL: U9.22 (MUX_SEL); also elsewhere on the board
GND: C82.2, C83.2, C84.1, J9.3, J10.3, J11.3, J12.3, J13.3, R40.2, SW1.4, SW1.MP, SW2.2, U9.7 (VSS); also elsewhere on the board
unnamed: J9.2, U9.11 (Volume)
unnamed: J10.2, U9.12 (L/R)
unnamed: J11.2, U9.13 (EQ_low)
unnamed: J12.2, U9.14 (EQ_midle)
unnamed: J13.2, U9.15 (EQ_high)
unnamed: R38.1, R39.2, SW1.2
unnamed: R38.2, R40.1, SW1.3
unnamed: R42.1, SW2.1, U9.48 (PAIR_BT)
unnamed: SW1.5, U9.16 (Source)

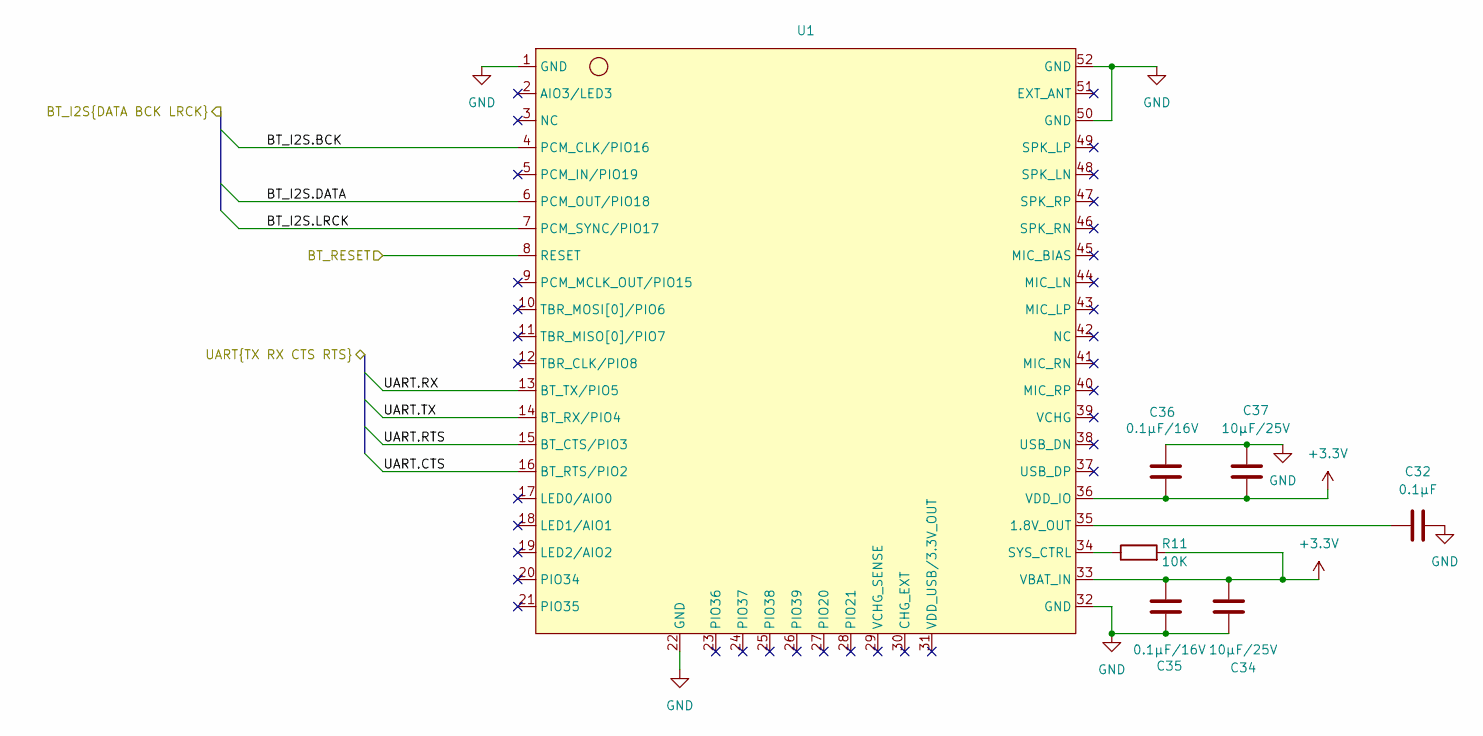
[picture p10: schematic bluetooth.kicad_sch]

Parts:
C32: 0.1µF; C_01005_0402Metric
C34, C37: 10µF/25V; C_0805_2012Metric
C35, C36: 0.1µF/16V; C_0402_1005Metric
R11: 10K; R_0402_1005Metric
U1: FSC-BT1058

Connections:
+3.3V: C34.1, C35.1, C36.1, C37.1, R11.2, U1.33 (VBAT_IN), U1.36 (VDD_IO); also elsewhere on the board
/Bluetooth/BT_I2S.BCK: U1.4 (PCM_CLK/PIO16); also elsewhere on the board
/Bluetooth/BT_I2S.DATA: U1.6 (PCM_OUT/PIO18); also elsewhere on the board
/Bluetooth/BT_I2S.LRCK: U1.7 (PCM_SYNC/PIO17); also elsewhere on the board
/Bluetooth/BT_RESET: U1.8 (RESET); also elsewhere on the board
/Bluetooth/UART.CTS: U1.16 (BT_RTS/PIO2); also elsewhere on the board
/Bluetooth/UART.RTS: U1.15 (BT_CTS/PIO3); also elsewhere on the board
/Bluetooth/UART.RX: U1.13 (BT_TX/PIO5); also elsewhere on the board
/Bluetooth/UART.TX: U1.14 (BT_RX/PIO4); also elsewhere on the board
GND: C32.2, C34.2, C35.2, C36.2, C37.2, U1.1 (GND), U1.22 (GND), U1.32 (GND), U1.50 (GND), U1.52 (GND); also elsewhere on the board
unnamed: C32.1, U1.35 (1.8V_OUT)
unnamed: R11.1, U1.34 (SYS_CTRL)

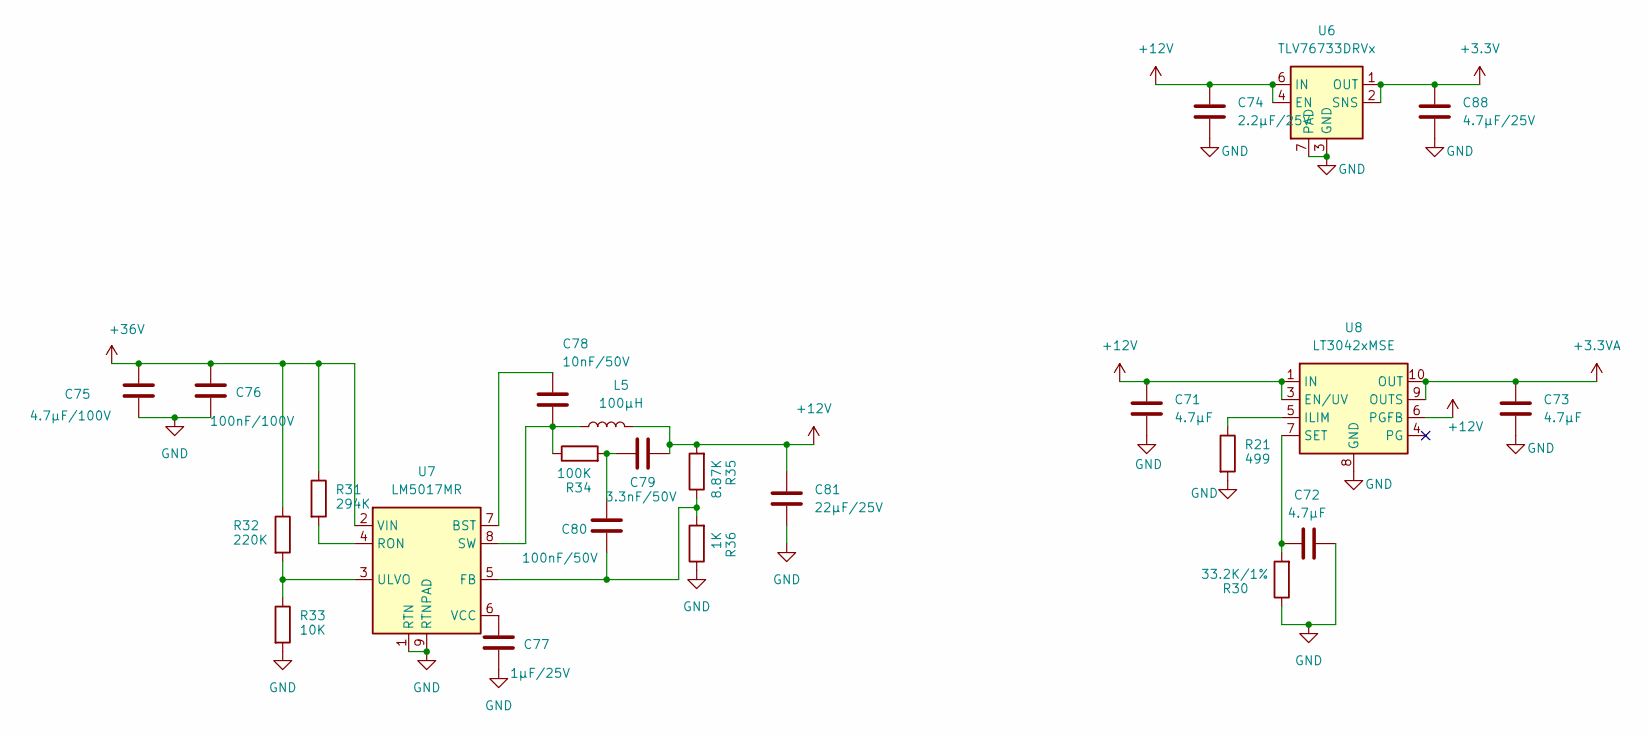
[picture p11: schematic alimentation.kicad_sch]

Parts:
C71, C72, C73: 4.7µF; C_0805_2012Metric
C74: 2.2µF/25V; C_0603_1608Metric
C75: 4.7µF/100V; C_1210_3225Metric
C76: 100nF/100V; C_0805_2012Metric
C77: 1µF/25V; C_0805_2012Metric
C78: 10nF/50V; C_0603_1608Metric
C79: 3.3nF/50V; C_0603_1608Metric
C80: 100nF/50V; C_0603_1608Metric
C81: 22µF/25V; C_1210_3225Metric
C88: 4.7µF/25V; C_0603_1608Metric
L5: 100µH; L_Bourns_SRR1260
R21: 499; R_0201_0603Metric
R30: 33.2K/1%; R_0805_2012Metric
R31: 294K; R_0603_1608Metric
R32: 220K; R_0603_1608Metric
R33: 10K; R_0603_1608Metric
R34: 100K; R_0603_1608Metric
R35: 8.87K; R_0603_1608Metric
R36: 1K; R_0603_1608Metric
U6: TLV76733DRVx; WSON-6-1EP_2x2mm_P0.65mm_EP1x1.6mm_ThermalVias
U7: LM5017MR; SOIC-8-1EP_3.9x4.9mm_P1.27mm_EP2.95x4.9mm_Mask2.71x3.4mm_Th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
U8: LT3042xMSE; MSOP-10-1EP_3x3mm_P0.5mm_EP1.68x1.88mm

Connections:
+3.3V: C88.1, U6.1 (OUT), U6.2 (SNS); also elsewhere on the board
+3.3VA: C73.1, U8.9 (OUTS), U8.10 (OUT); also elsewhere on the board
+12V: C71.1, C74.1, C79.2, C81.1, L5.2, R35.2, U6.4 (EN), U6.6 (IN), U8.1 (IN), U8.2 (IN), U8.3 (EN/UV), U8.6 (PGFB); also elsewhere on the board
+36V: C75.2, C76.2, R31.1, R32.1, U7.2 (VIN); also elsewhere on the board
GND: C71.2, C72.2, C73.2, C74.2, C75.1, C76.1, C77.1, C81.2, C88.2, R21.2, R30.1, R33.2, R36.1, U6.3 (GND), U6.5 (GND), U6.7 (PAD), U7.1 (RTN), U7.9 (RTNPAD), U8.8 (GND), U8.11 (GND); also elsewhere on the board
unnamed: C79.1, C80.2, R34.2
unnamed: C78.1, U7.7 (BST)
unnamed: C80.1, R35.1, R36.2, U7.5 (FB)
unnamed: R31.2, U7.4 (RON)
unnamed: C78.2, L5.1, R34.1, U7.8 (SW)
unnamed: R32.2, R33.1, U7.3 (ULVO)
unnamed: C77.2, U7.6 (VCC)
unnamed: R21.1, U8.5 (ILIM)
unnamed: C72.1, R30.2, U8.7 (SET)

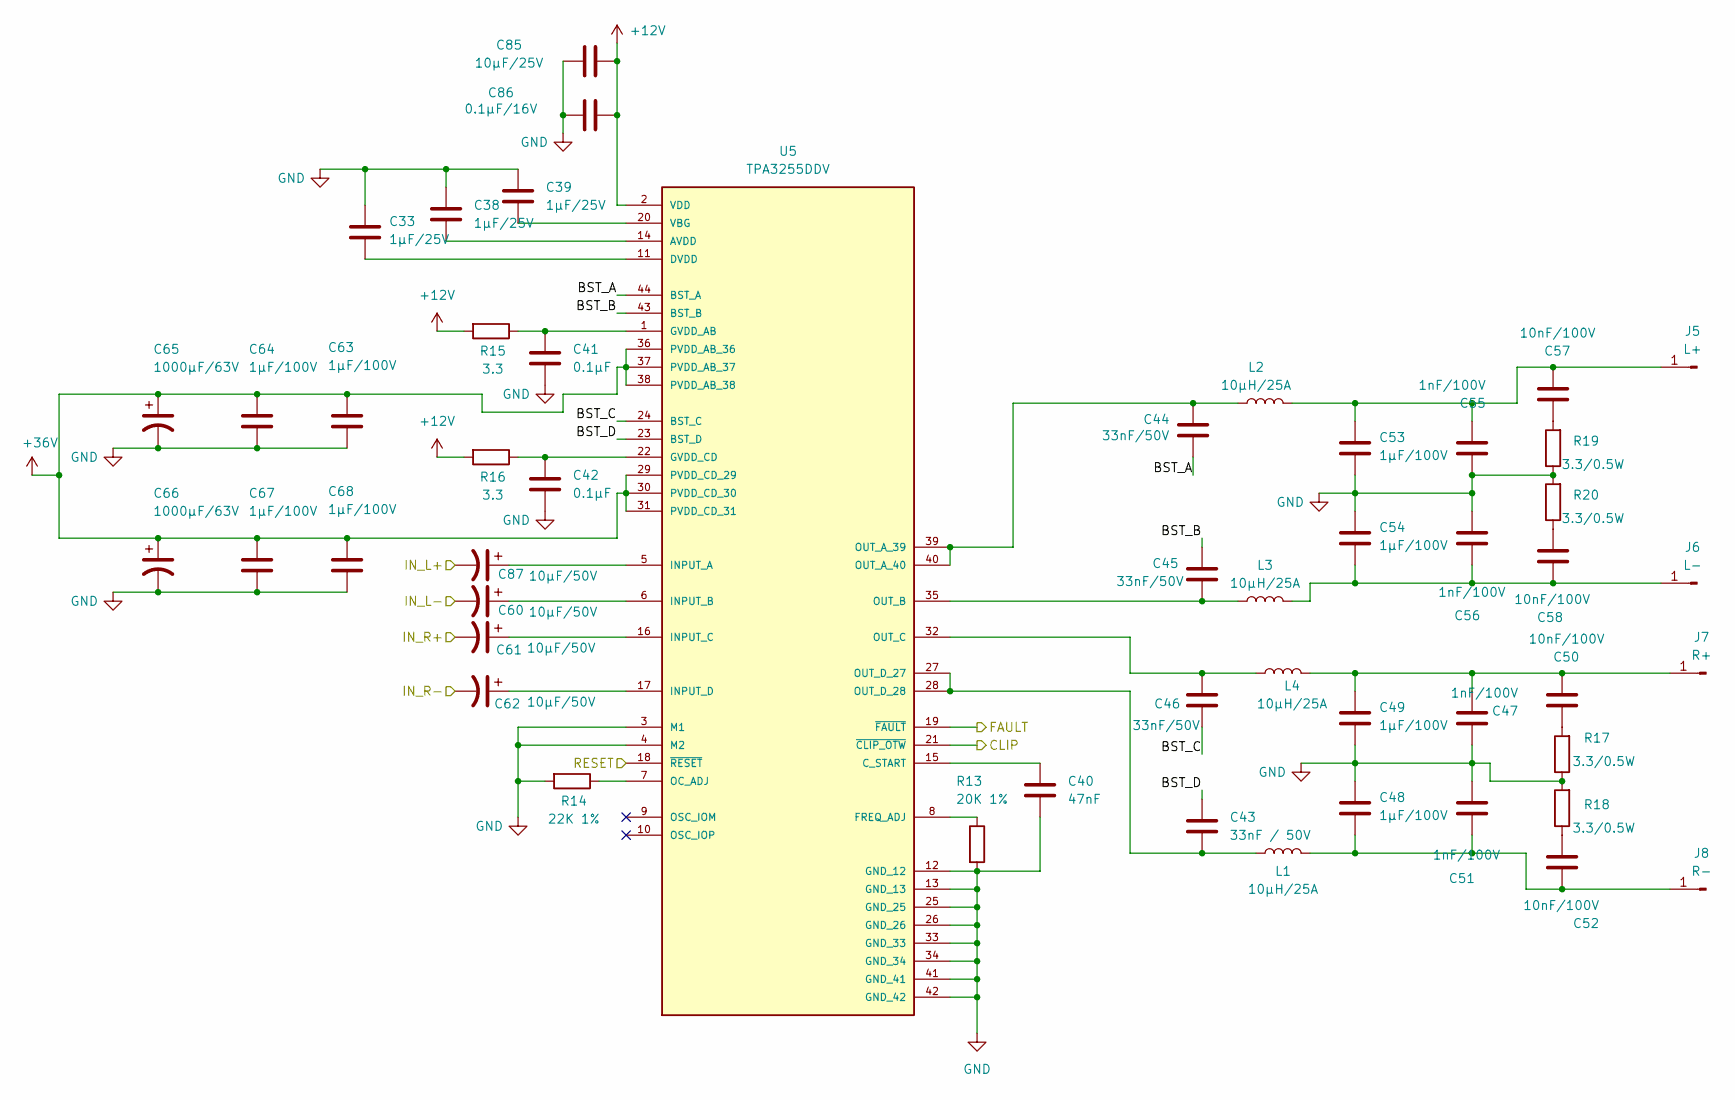
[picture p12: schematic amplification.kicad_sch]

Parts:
C33, C38, C39: 1µF/25V; C_0603_1608Metric
C40: 47nF; C_0201_0603Metric
C41, C42: 0.1µF; C_0603_1608Metric
C43: 33nF / 50V; C_0603_1608Metric
C44, C45, C46: 33nF/50V; C_0603_1608Metric
C47, C51, C55, C56: 1nF/100V; C_0201_0603Metric
C48, C49, C53, C54: 1µF/100V; C_Rect_L10.0mm_W4.0mm_P7.50mm_MKS4
C50, C52, C57, C58: 10nF/100V; C_0805_2012Metric
C60, C61, C62, C87: 10µF/50V; CP_Radial_D6.3mm_P2.50mm
C63, C64, C67, C68: 1µF/100V; C_1206_3216Metric
C65, C66: 1000µF/63V; CP_Radial_D16.0mm_P7.50mm
C85: 10µF/25V; C_0805_2012Metric
C86: 0.1µF/16V; C_0402_1005Metric
J5: L+; SolderWirePad_1x01_SMD_2x4mm
J6: L-; SolderWirePad_1x01_SMD_2x4mm
J7: R+; SolderWirePad_1x01_SMD_2x4mm
J8: R-; SolderWirePad_1x01_SMD_2x4mm
L1, L2, L3, L4: 10µH/25A; IND_SER2915L-103KL
R13: 20K 1%; R_0805_2012Metric
R14: 22K 1%; R_0805_2012Metric
R15, R16: 3.3; R_0201_0603Metric
R17, R18, R19, R20: 3.3/0.5W; R_1206_3216Metric
U5: TPA3255DDV; TPA3255; PARTREV A

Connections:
+12V: C85.1, C86.1, R15.2, R16.2, U5.2 (VDD); also elsewhere on the board
+36V: C63.1, C64.1, C65.1, C66.1, C67.1, C68.1, U5.29 (PVDD_CD_29), U5.30 (PVDD_CD_30), U5.31 (PVDD_CD_31), U5.36 (PVDD_AB_36), U5.37 (PVDD_AB_37), U5.38 (PVDD_AB_38); also elsewhere on the board
/Amplification/BST_A: C44.2, U5.44 (BST_A)
/Amplification/BST_B: C45.1, U5.43 (BST_B)
/Amplification/BST_C: C46.2, U5.24 (BST_C)
/Amplification/BST_D: C43.1, U5.23 (BST_D)
/Amplification/CLIP: U5.21 (~CLIP_OTW)
/Amplification/FAULT: U5.19 (~FAULT); also elsewhere on the board
/Amplification/IN_L+: C87.2; also elsewhere on the board
/Amplification/IN_L-: C60.2; also elsewhere on the board
/Amplification/IN_R+: C61.2; also elsewhere on the board
/Amplification/IN_R-: C62.2; also elsewhere on the board
/Amplification/RESET: U5.18 (~RESET); also elsewhere on the board
GND: C33.1, C38.2, C39.2, C40.2, C41.1, C42.1, C47.1, C48.1, C49.2, C51.2, C53.2, C54.1, C55.1, C56.2, C63.2, C64.2, C65.2, C66.2, C67.2, C68.2, C85.2, C86.2, R13.2, R14.2, R17.1, R18.2, R19.1, R20.2, U5.3 (M1), U5.4 (M2), U5.12 (GND_12), U5.13 (GND_13), U5.25 (GND_25), U5.26 (GND_26), U5.33 (GND_33), U5.34 (GND_34), U5.41 (GND_41), U5.42 (GND_42); also elsewhere on the board
unnamed: C50.1, R17.2
unnamed: C52.2, R18.1
unnamed: C57.1, R19.2
unnamed: C58.2, R20.1
unnamed: C53.1, C55.2, C57.2, J5.1 (Pin_1_1), L2.2
unnamed: C54.2, C56.1, C58.1, J6.1 (Pin_1_1), L3.2
unnamed: C47.2, C49.1, C50.2, J7.1 (Pin_1_1), L4.2
unnamed: C48.2, C51.1, C52.1, J8.1 (Pin_1_1), L1.2
unnamed: C38.1, U5.14 (AVDD)
unnamed: C40.1, U5.15 (C_START)
unnamed: C33.2, U5.11 (DVDD)
unnamed: R13.1, U5.8 (FREQ_ADJ)
unnamed: C41.2, R15.1, U5.1 (GVDD_AB)
unnamed: C42.2, R16.1, U5.22 (GVDD_CD)
unnamed 91: C87.1, U5.5 (INPUT_A); also elsewhere on the board
unnamed 92: C60.1, U5.6 (INPUT_B); also elsewhere on the board
unnamed 93: C61.1, U5.16 (INPUT_C); also elsewhere on the board
unnamed 94: C62.1, U5.17 (INPUT_D); also elsewhere on the board
unnamed: R14.1, U5.7 (OC_ADJ)
unnamed: C44.1, L2.1, U5.39 (OUT_A_39), U5.40 (OUT_A_40)
unnamed: C45.2, L3.1, U5.35 (OUT_B)
unnamed: C46.1, L4.1, U5.32 (OUT_C)
unnamed: C43.2, L1.1, U5.27 (OUT_D_27), U5.28 (OUT_D_28)
unnamed: C39.1, U5.20 (VBG)

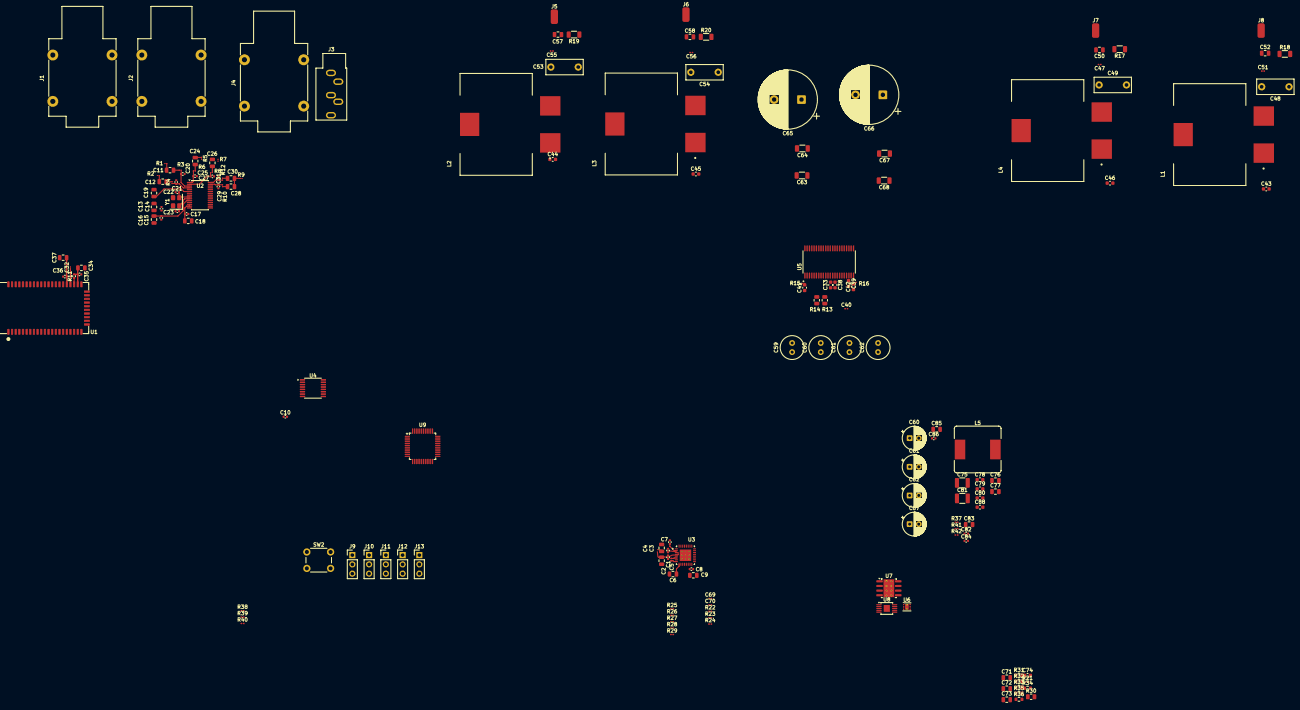
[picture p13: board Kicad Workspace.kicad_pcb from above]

Board: 2 copper layers, 162 parts (0 on the bottom side), 109 nets.

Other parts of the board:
C59: 10µF/50V; C_Radial_D6.3mm_H11.0mm_P2.50mm
C60#2, C61#2, C62#2: 10µF/50V; CP_Radial_D6.3mm_P2.50mm

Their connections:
/Amplification/IN_L+: C59.2; also elsewhere on the board
/Amplification/IN_L-: C60#2.2; also elsewhere on the board
/Amplification/IN_R+: C61#2.2; also elsewhere on the board
/Amplification/IN_R-: C62#2.2; also elsewhere on the board
unnamed 91: C59.1; also elsewhere on the board
unnamed 92: C60#2.1; also elsewhere on the board
unnamed 93: C61#2.1; also elsewhere on the board
unnamed 94: C62#2.1; also elsewhere on the board

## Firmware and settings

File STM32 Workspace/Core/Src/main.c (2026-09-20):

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
/* Includes ------------------------------------------------------------------*/
#include "main.h"

/* USER CODE BEGIN Includes */
#include "pcm5242/pcm5242.h"
/* USER CODE END Includes */

/* USER CODE BEGIN PTD */
#define FIFO_SIZE 256

typedef struct {
	uint8_t d[FIFO_SIZE];
	uint16_t head;
	uint16_t tail;
} Fifo;
/* USER CODE END PTD */

I2C_HandleTypeDef hi2c1;

TIM_HandleTypeDef htim1;

UART_HandleTypeDef huart1;
UART_HandleTypeDef huart2;

/* USER CODE BEGIN PV */
static Fifo to_pc; // octets venant du module, en attente d'envoi au PC
static Fifo to_bt; // octets venant du PC, en attente d'envoi au module
/* USER CODE END PV */

void SystemClock_Config(void);
static void MX_GPIO_Init(void);
static void MX_TIM1_Init(void);
static void MX_USART1_UART_Init(void);
static void MX_I2C1_Init(void);
static void MX_USART2_UART_Init(void);
/* USER CODE BEGIN 0 */
/* Range dans le tampon l'octet recu, s'il y en a un. Ne bloque jamais. */
static void fifo_rx(UART_HandleTypeDef *src, Fifo *f) {
	USART_TypeDef *u = src->Instance;

	if (u->ISR & (USART_ISR_ORE | USART_ISR_FE | USART_ISR_NE)) {
		u->ICR = USART_ICR_ORECF | USART_ICR_FECF | USART_ICR_NECF;
	}

	if (u->ISR & USART_ISR_RXNE_RXFNE) {
		uint8_t c = (uint8_t) u->RDR;
		uint16_t next = (f->head + 1) % FIFO_SIZE;
		if (next != f->tail) {
			f->d[f->head] = c;
			f->head = next;
		}
	}
}

/* Sort du tampon un octet vers l'UART, s'il est libre. Ne bloque jamais. */
static void fifo_tx(UART_HandleTypeDef *dst, Fifo *f) {
	USART_TypeDef *u = dst->Instance;

	if (f->head != f->tail && (u->ISR & USART_ISR_TXE_TXFNF)) {
		u->TDR = f->d[f->tail];
		f->tail = (f->tail + 1) % FIFO_SIZE;
	}
}

/* Lit src, puis envoie vers dst ce que le tampon contient */
static void bridge(UART_HandleTypeDef *src, UART_HandleTypeDef *dst, Fifo *f) {
	fifo_rx(src, f);
	fifo_tx(dst, f);
}
/* USER CODE END 0 */

/**
  * @brief  The application entry point.
  * @retval int
  */
int main(void)
{

  /* MCU Configuration--------------------------------------------------------*/

  /* Reset of all peripherals, Initializes the Flash interface and the Systick. */
  HAL_Init();

  /* Configure the system clock */
  SystemClock_Config();

  /* Initialize all configured peripherals */
  MX_GPIO_Init();
  MX_TIM1_Init();
  MX_USART1_UART_Init();
  MX_I2C1_Init();
  MX_USART2_UART_Init();
  /* USER CODE BEGIN 2 */
  const char banner[] = "\r\n---debut de loop ---\r\n";
  HAL_UART_Transmit(&huart2, (uint8_t*) banner, sizeof(banner) - 1, 100);
  /* USER CODE END 2 */

  /* Infinite loop */
  /* USER CODE BEGIN WHILE */
  while (1)
  {
    /* USER CODE END WHILE */

    /* USER CODE BEGIN 3 */
    bridge(&huart1, &huart2, &to_pc); // module BT -> PC
    bridge(&huart2, &huart1, &to_bt); // PC -> module BT
    bool checked = pcm5242_checkCom(&hi2c1);
    uint32_t a = 0;
  }
  /* USER CODE END 3 */
}

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


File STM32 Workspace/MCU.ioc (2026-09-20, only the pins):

Mcu.UserName=STM32G030C8Tx
PA10.Signal=USART1_RX
PA2.Signal=USART2_TX
PA3.Signal=USART2_RX
PA5.Signal=ADC1_IN5
PA9.Signal=USART1_TX
PB10.Signal=GPIO_Output
PB11.Signal=GPIO_Output
PB12.Signal=GPIO_Output
PB13.Signal=GPIO_Output
PB14.Signal=GPIO_Input
PB6.Signal=I2C1_SCL
PB7.Signal=I2C1_SDA
PB9.Signal=GPIO_Input

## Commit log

2026-05-28 more doc (MUX + ADC)
2026-05-31 kicad project
    [Kicad Workspace.kicad_pcb, Kicad Workspace.kicad_sch, PCM5242RHBT.step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]
2026-06-01 feat: MUX + DAC Kicad schematics done
    [eq_and_dac.kicad_sch, untitled.kicad_sch]
2026-06-02 Wire input (ADC) schematics done
    [Kicad Workspace.kicad_sch, mcu.kicad_sch, wired_input.kicad_sch]
2026-06-03 feat: Bluetooth FSC BT1058 schematics done
    [bluetooth.kicad_sch]
2026-06-03 feat: ampli stage work in progress
    [amplification.kicad_sch]
2026-06-03 pro and sch update
    [Kicad Workspace.kicad_sch]
2026-06-03 project update
    [Kicad Workspace.kicad_sch]
2026-06-04 feat: filtering analog output
    [eq_and_dac.kicad_sch]
2026-06-04 feat: TPA3255 power 48V + clean output
    [amplification.kicad_sch]
2026-06-04 feat: project global
    [Kicad Workspace.kicad_sch]
2026-06-06 feat: alimentation stage almost done
    [alimentation.kicad_sch]
2026-06-06 fix: split analog 3.3 from digital 3.3
    [eq_and_dac.kicad_sch, wired_input.kicad_sch]
2026-06-06 feat: calculator for the LM5017 capa/resistor values
    [LM5017QuickStartCalculator.xls]
2026-06-07 feat: alim stage done + adapt to 36V input voltage instead of 48
    [alimentation.kicad_sch, amplification.kicad_sch]
2026-06-08 feat: mcu stm32 stack project
2026-06-08 feat: kicad mcu routing work in progress
    [mcu.kicad_sch]
2026-06-08 feat: mcu routing work in progress
    [mcu.kicad_sch]
2026-06-09 feat: pin declaration cube MX + 2DC + 1 ADC channel
2026-06-09 feat: kicad mcu symbole modif to match pins
    [mcu.kicad_sch]
2026-06-10 feat: schematics almost done, starting to correct compile pb
    [Kicad Workspace.kicad_sch, bluetooth.kicad_sch, eq_and_dac.kicad_sch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]
2026-06-10 feat: correction work in progress
    [alimentation.kicad_sch, bluetooth.kicad_sch, eq_and_dac.kicad_sch]
2026-06-11 feat: start of routing
    [Kicad Workspace.kicad_pcb]
2026-06-14 feat: BT1058 footprint
2026-06-14 feat: BT-1058 footprint name update
    [bluetooth.kicad_sch]
2026-06-14 feat: adding jack connectors on PCB
    [wired_input.kicad_sch]
2026-06-15 ressources: jack 3d files
    [3D Model NMJ4HFD2.stp, Same_Sky_SJ1-3535NG.step]
2026-06-15 feat: jack schematics
    [wired_input.kicad_sch]
2026-06-15 fix: Bus fix with correct syntax
    [Kicad Workspace.kicad_sch, amplification.kicad_sch, bluetooth.kicad_sch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]
2026-06-15 ressource: PCM5242 & TPA3255 footprint
2026-06-15 feat: routing work in progress
    [Kicad Workspace.kicad_pcb, eq_and_dac.kicad_sch]
2026-06-16 feat: potentiometers + source switch + bt pari button
    [mcu.kicad_sch]
2026-06-17 feat: selecting TPA3255 output inductances
    [SER2915L-103KL.step, amplification.kicad_sch]
2026-06-17 feat: routing TPA3255 output components placement
    [Kicad Workspace.kicad_pcb]
2026-09-20 ressources: regroupement des datasheets dans Ressources/Datasheet
2026-09-20 docs: ajout du README de présentation du projet
2026-09-20 ressource: complete datasheet set with searchable text and index
    Adds 8 missing PDFs named by schematic ref, a grepable txt/ dump and an index.
2026-09-20 fix: schematic corrections from the datasheet audit
    Adds I2C/PAIR_BT pull-ups, STM32 and TPA3255 decoupling, VREF+ link; pots moved to +3.3V.
    [amplification.kicad_sch, mcu.kicad_sch]
2026-09-20 feat: STM32 first debug
    [MCU Debug.cfg]
2026-09-20 chore: ignore STM32 Debug build folder
2026-09-27 Remove flowchart from README
    Removed mermaid diagram from the overview section.
2026-09-30 feat: calcul des coefs custom et début d'écriture mémoire dsp
2026-10-01 ressource: datasheet de filtrage sur PCM5242
2026-10-08 feat: kicad alim stage clean up + TPA stage clean up
    [Kicad Workspace.kicad_pcb, alimentation.kicad_sch, amplification.kicad_sch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]

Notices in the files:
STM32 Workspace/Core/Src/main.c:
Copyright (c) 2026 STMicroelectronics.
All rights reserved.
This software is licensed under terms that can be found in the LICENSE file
